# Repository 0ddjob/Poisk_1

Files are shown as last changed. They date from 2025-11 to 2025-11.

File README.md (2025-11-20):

# Poisk 1
Information about the Ukrainian SSR IBM PC/XT compatible.

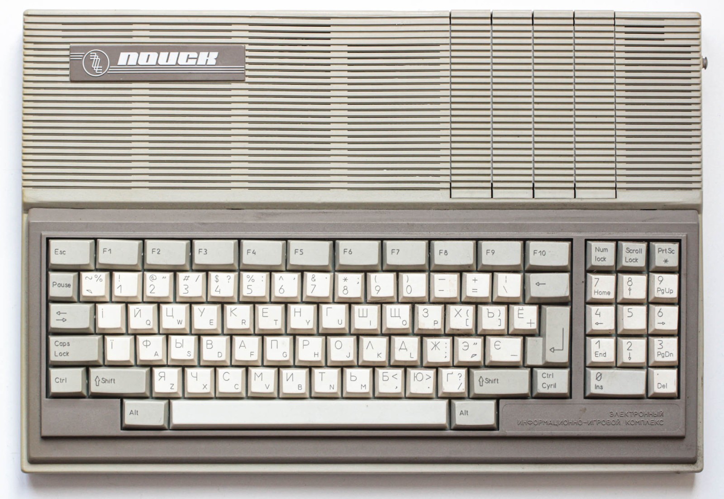
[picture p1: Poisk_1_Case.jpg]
Poisk 1 case


## [Analogue RGB to VGA Converter](/Poisk_1_RGB_DIN-to-VGA)
A simple board to convert the physical interface from a 7-pin DIN to standard VGA DE15 & 3.5mm sockets.<br>

- Pin 1 = red
- Pin 2 = GND
- Pin 3 = green
- Pin 4 = blue
- Pin 5 = composite sync.
- Pin 6 = audio
- Pin 7 = intensity

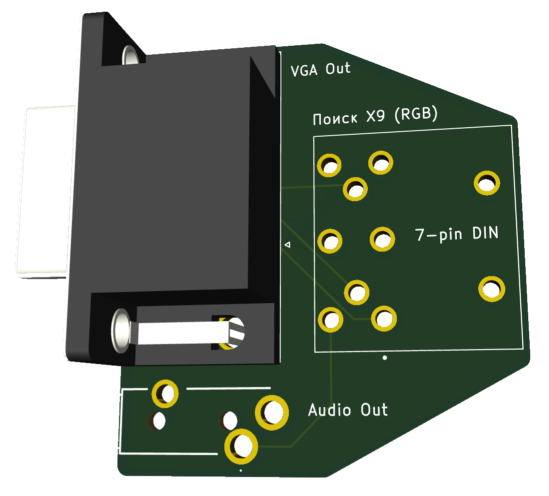
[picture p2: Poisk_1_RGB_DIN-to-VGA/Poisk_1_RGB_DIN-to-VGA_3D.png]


## [Monochrome Video to RCA Converter](/Poisk_1_Video_DIN-to-RCA)
A simple board to convert the physical interface from a 5-pin DIN to standard RCA sockets.<br>

- Pin 1 = audio
- Pin 2 = GND
- Pin 3 = +12V
- Pin 4 = +5V
- Pin 5 = video (monochrome)

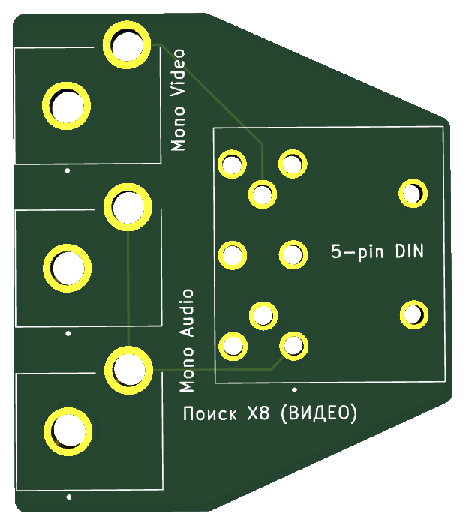
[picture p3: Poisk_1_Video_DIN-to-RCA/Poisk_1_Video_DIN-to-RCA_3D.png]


## [Digital RGB to CGA/EGA Converter](/Poisk_1_SYNC_DIN-to-CGA)
A simple board to convert the physical interface from a 7-pin DIN to standard CGA/EGA DE9 socket.<br>

- Pin 1 = red
- Pin 2 = GND
- Pin 3 = green
- Pin 4 = blue
- Pin 5 = intensity
- Pin 6 = horizontal sync
- Pin 7 = vertical sync

## [Cassette to 3.5mm Audio Jack Converter](https://github.com/0ddjob/Conversion_Boards/tree/main/DIN-to-Audio_Jack)
A simple board to convert the physical interface from a 5-pin DIN to standard 3.5mm audio jacks.<br>

## [Datasheets](/Datasheets)
Relevant datasheets for parts used in the PCB designs.<br>

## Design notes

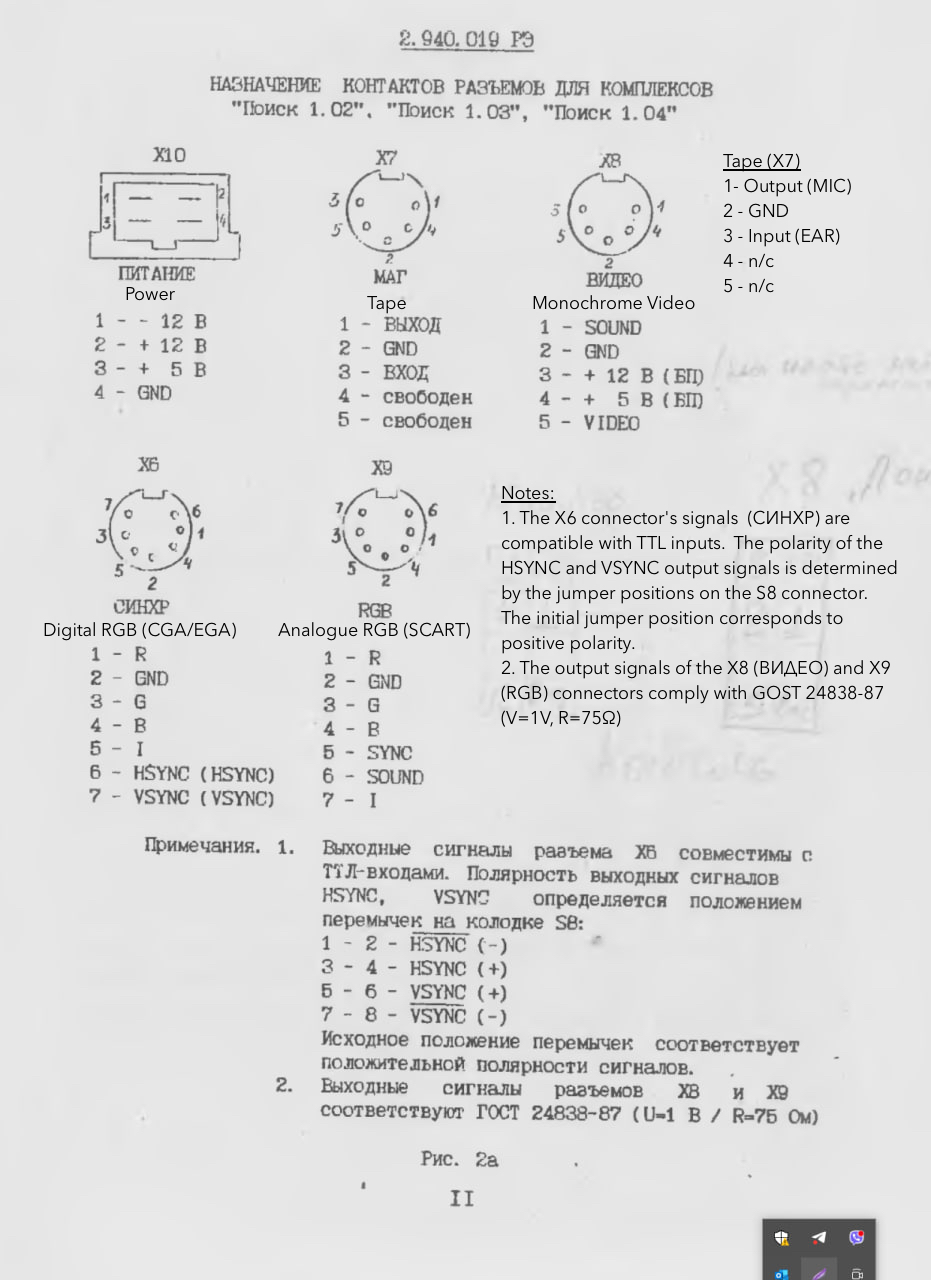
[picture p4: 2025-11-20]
Poisk_1_Pinouts.jpg

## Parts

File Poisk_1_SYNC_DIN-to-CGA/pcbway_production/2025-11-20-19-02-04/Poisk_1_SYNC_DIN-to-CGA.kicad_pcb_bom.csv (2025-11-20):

Designator | Quantity | Value | Footprint | Package | MPN | DNP | Mount_Type | Description | Height | Manufacturer_Name
J1 | 1 | Поиск 1 X6 (Digital RGB) | 6710801 |  | 671-0801 |  | tht | Deltron 8 Pole Right Angle Din Socket Socket, 2A, 100 V ac, Lockable | 19.5 | DELTRON COMPONENTS
J2 | 1 | CGA Out | DSUB-9_Pins_Horizontal_P2.77x2.84mm_EdgePinOffset7.70mm_Housed_MountingHolesOffset9.12mm |  |  |  | tht | 9-pin D-SUB connector, socket (female)

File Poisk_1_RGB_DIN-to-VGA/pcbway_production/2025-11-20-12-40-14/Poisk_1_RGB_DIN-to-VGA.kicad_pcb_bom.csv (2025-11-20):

Designator | Quantity | Value | Footprint | Package | MPN | DNP | Mount_Type | Description | Height | Manufacturer_Name | Mouser Part Number | Mouser Price/Stock
J1 | 1 | Поиск 1 X9 (Analogue RGB) | 6710801 |  | 671-0801 |  | tht | Deltron 8 Pole Right Angle Din Socket Socket, 2A, 100 V ac, Lockable | 19.5 | DELTRON COMPONENTS
J2 | 1 | VGA Out | DSUB-15-HD_Socket_Horizontal_P2.29x2.54mm_EdgePinOffset8.35mm_Housed_MountingHolesOffset10.89mm |  |  |  | tht | 15-pin D-SUB connector, socket (female), High density (3 columns), Triple Row, Generic, VGA-connector
J3 | 1 | Audio Out | SJ3350820BTR |  | SJ3-350820B-TR |  | tht | 3.5 mm Stereo Jack, Through Hole, 2 Conductors, 1 Internal Switches, Tape & Reel Packaging | 5.3 | Same Sky | 179-SJ3-350820B-TR | https://www.mouser.co.uk/ProductDetail/Same-Sky/SJ3-350820B-TR?qs=IKkN%2F947nfBCsohFK16iQg%3D%3D

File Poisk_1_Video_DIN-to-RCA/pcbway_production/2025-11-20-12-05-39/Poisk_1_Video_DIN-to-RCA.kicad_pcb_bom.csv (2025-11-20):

Designator | Quantity | Value | Footprint | Package | MPN | DNP | Mount_Type | Description | Height | Manufacturer_Name
J1 | 1 | Поиск 1 X8 (Видео) | 6710801 |  | 671-0801 |  | tht | Deltron 8 Pole Right Angle Din Socket Socket, 2A, 100 V ac, Lockable | 19.5 | DELTRON COMPONENTS
J2 | 1 | Video | FC68371 |  | FC68371 |  | tht | Socket; RCA; female; angled 90; THT; nickel plated; Marker: black | 14 | CLIFF ELECTRONIC COMPONENTS
J3 | 1 | Audio (L) | FC68371 |  | FC68371 |  | tht | Socket; RCA; female; angled 90; THT; nickel plated; Marker: black | 14 | CLIFF ELECTRONIC COMPONENTS
J4 | 1 | Audio (R) | FC68371 |  | FC68371 |  | tht | Socket; RCA; female; angled 90; THT; nickel plated; Marker: black | 14 | CLIFF ELECTRONIC COMPONENTS

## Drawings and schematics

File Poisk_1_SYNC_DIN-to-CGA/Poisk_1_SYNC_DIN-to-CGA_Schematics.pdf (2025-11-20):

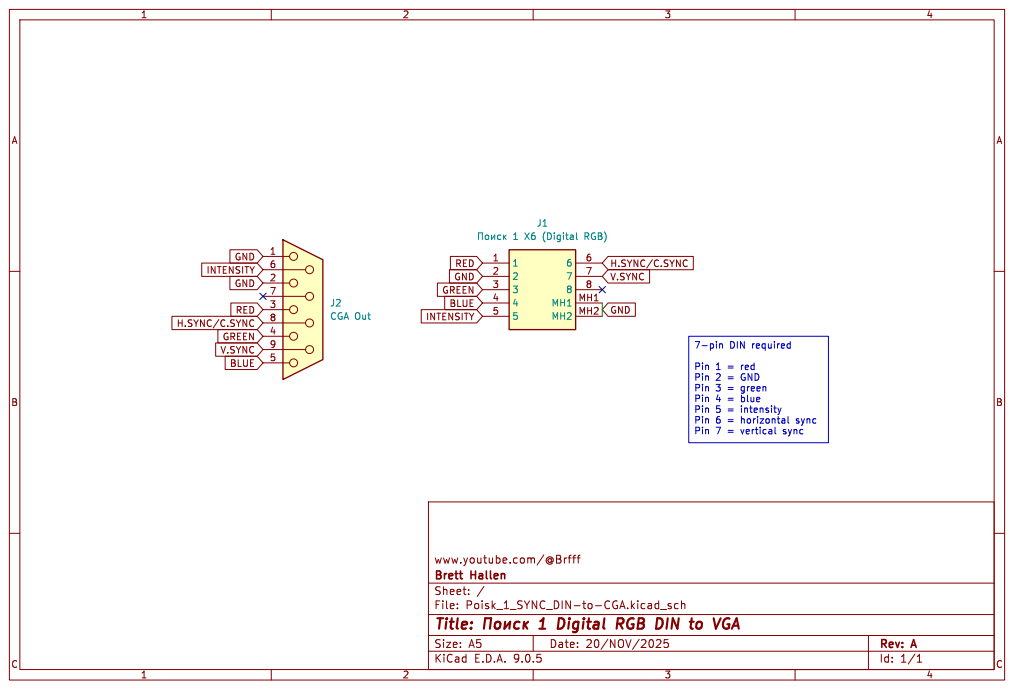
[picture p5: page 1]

www.youtube.com/@Brfff
Sheet: /
Title: þÿ>8A: 1 Digital RGB DIN to VGA

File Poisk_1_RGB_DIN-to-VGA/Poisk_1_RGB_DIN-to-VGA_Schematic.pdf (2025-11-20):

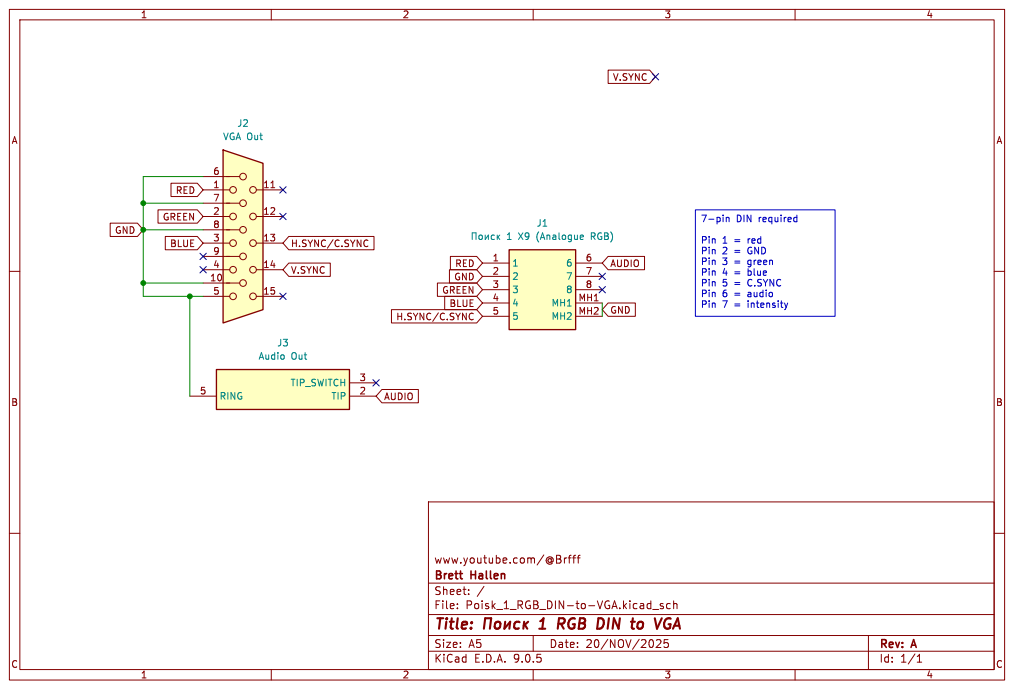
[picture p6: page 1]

www.youtube.com/@Brfff
Sheet: /
Title: þÿ>8A: 1 RGB DIN to VGA

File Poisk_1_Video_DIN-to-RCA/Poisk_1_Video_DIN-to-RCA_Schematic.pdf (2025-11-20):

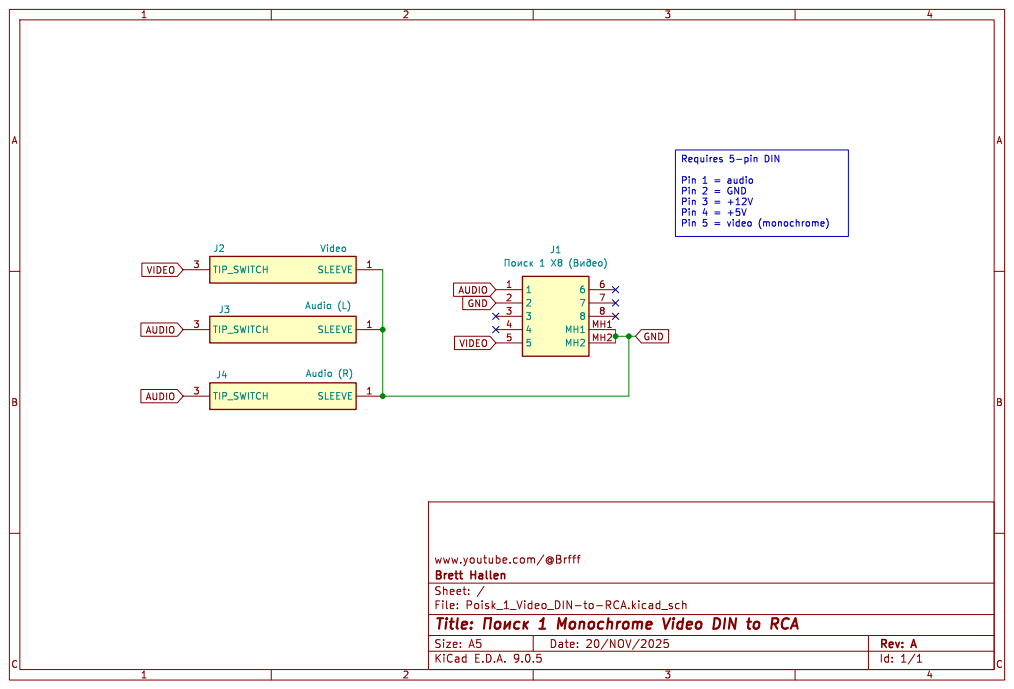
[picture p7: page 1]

www.youtube.com/@Brfff
Sheet: /
Title: þÿ>8A: 1 Monochrome Video DIN to RCA

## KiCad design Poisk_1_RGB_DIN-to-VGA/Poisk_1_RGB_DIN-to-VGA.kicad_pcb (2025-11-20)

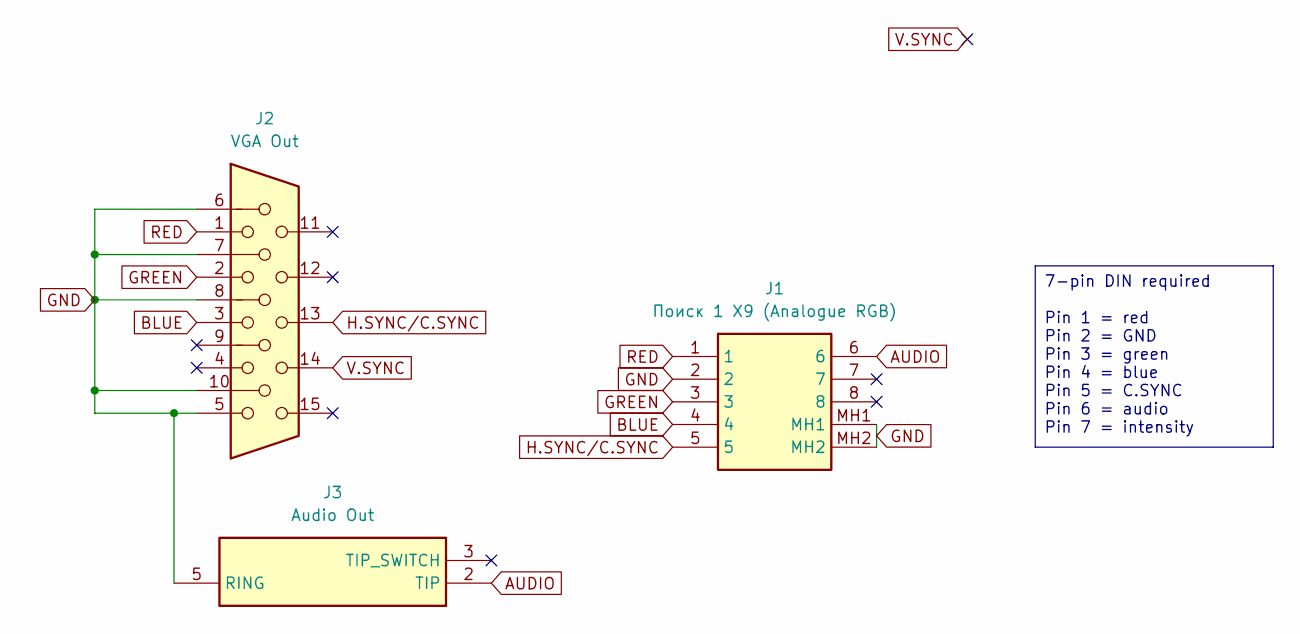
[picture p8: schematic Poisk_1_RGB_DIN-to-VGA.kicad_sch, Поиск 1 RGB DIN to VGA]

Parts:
J1: Поиск 1 X9 (Analogue RGB); 6710801; Manufacturer_Part_Number 671-0801
J2: VGA Out; DSUB-15-HD_Socket_Horizontal_P2.29x2.54mm_EdgePinOffset8.35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
J3: Audio Out; SJ3350820BTR; Mouser Part Number 179-SJ3-350820B-TR

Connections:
AUDIO: J1.6, J3.2 (TIP)
BLUE: J1.4, J2.3
GND: J1.2, J1.MH1, J1.MH2, J2.5, J2.6, J2.7, J2.8, J2.10, J3.5 (RING)
GREEN: J1.3, J2.2
H.SYNC/C.SYNC: J1.5, J2.13
RED: J1.1, J2.1
V.SYNC: J2.14

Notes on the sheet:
7-pin DIN required Pin 1 = red Pin 2 = GND Pin 3 = green Pin 4 = blue Pin 5 = C.SYNC Pin 6 = audio Pin 7 = intensity

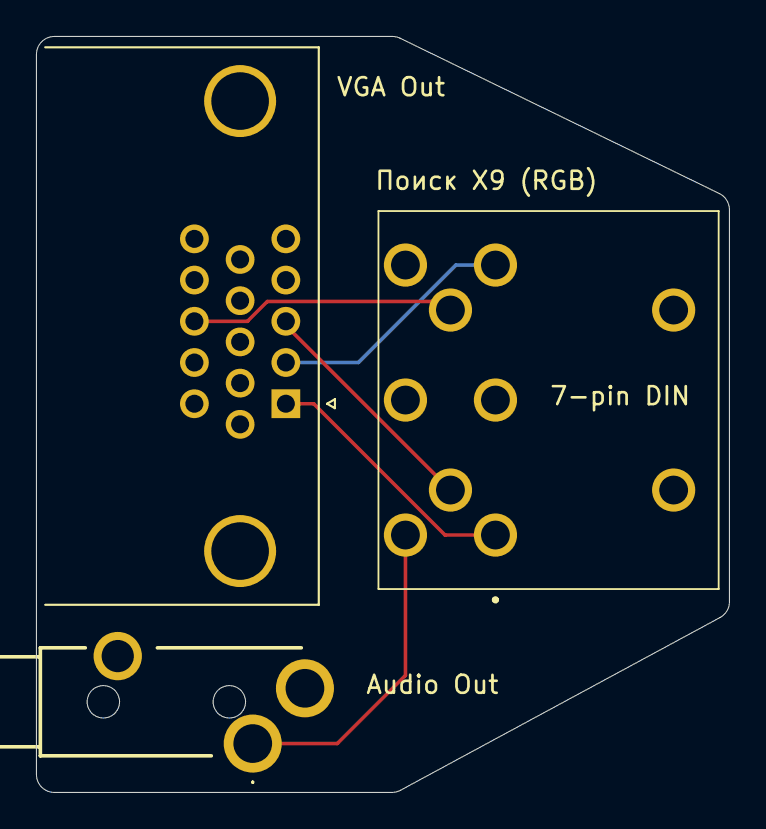
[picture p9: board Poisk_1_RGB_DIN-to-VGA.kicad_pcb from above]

Board: 2 copper layers, 38.5 x 42.0 mm, 3 parts (0 on the bottom side), 6 nets.

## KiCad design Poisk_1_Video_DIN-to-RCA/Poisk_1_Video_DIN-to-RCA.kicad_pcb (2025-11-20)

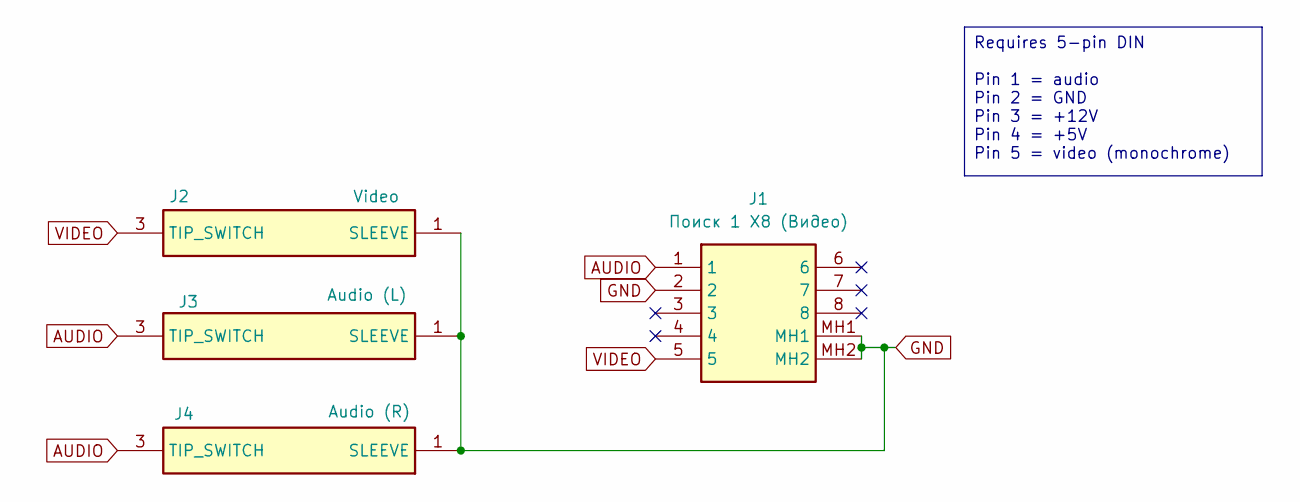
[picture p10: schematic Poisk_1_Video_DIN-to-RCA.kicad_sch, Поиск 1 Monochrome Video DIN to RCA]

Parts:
J1: Поиск 1 X8 (Видео); 6710801; Manufacturer_Part_Number 671-0801
J2: Video; FC68371; Manufacturer_Part_Number FC68371
J3: Audio (L); FC68371; Manufacturer_Part_Number FC68371
J4: Audio (R); FC68371; Manufacturer_Part_Number FC68371

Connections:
AUDIO: J1.1, J3.3 (TIP_SWITCH), J4.3 (TIP_SWITCH)
GND: J1.2, J1.MH1, J1.MH2, J2.1 (SLEEVE), J3.1 (SLEEVE), J4.1 (SLEEVE)
VIDEO: J1.5, J2.3 (TIP_SWITCH)

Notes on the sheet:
Requires 5-pin DIN Pin 1 = audio Pin 2 = GND Pin 3 = +12V Pin 4 = +5V Pin 5 = video (monochrome)

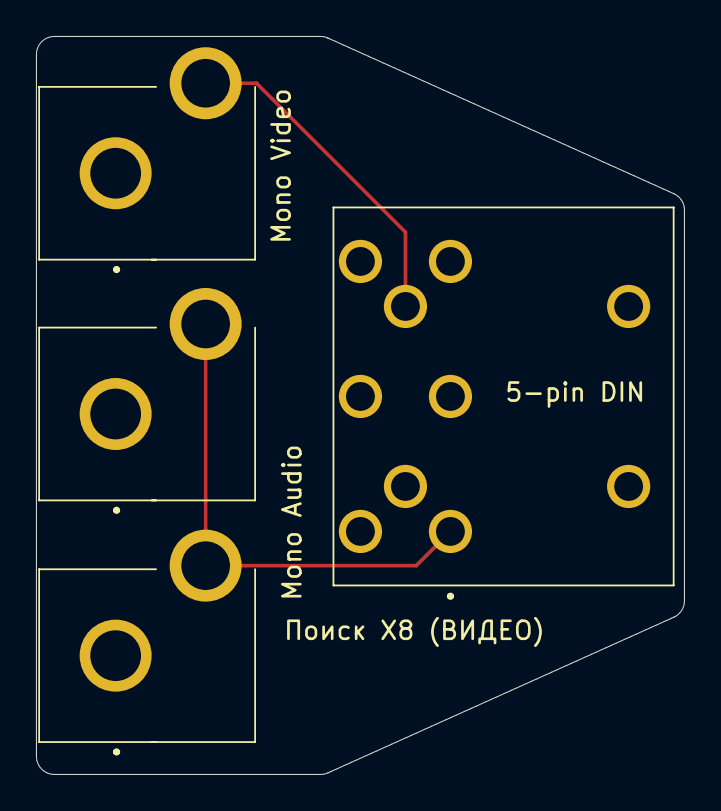
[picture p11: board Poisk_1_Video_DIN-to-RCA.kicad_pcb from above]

Board: 2 copper layers, 36.0 x 41.0 mm, 4 parts (0 on the bottom side), 3 nets.
